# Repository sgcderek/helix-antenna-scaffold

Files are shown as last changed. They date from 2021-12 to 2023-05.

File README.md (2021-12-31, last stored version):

This repository contains the major versions of the dereksgc helical antenna scaffold OpenSCAD files. These can be used to generate a completely customized scaffold for a helical antenna of any application (HRPT dish feed, Inmarsat antenna, Wifi, FPV, ...).

Short summary of each version included:

**Version 5 - LATEST**  
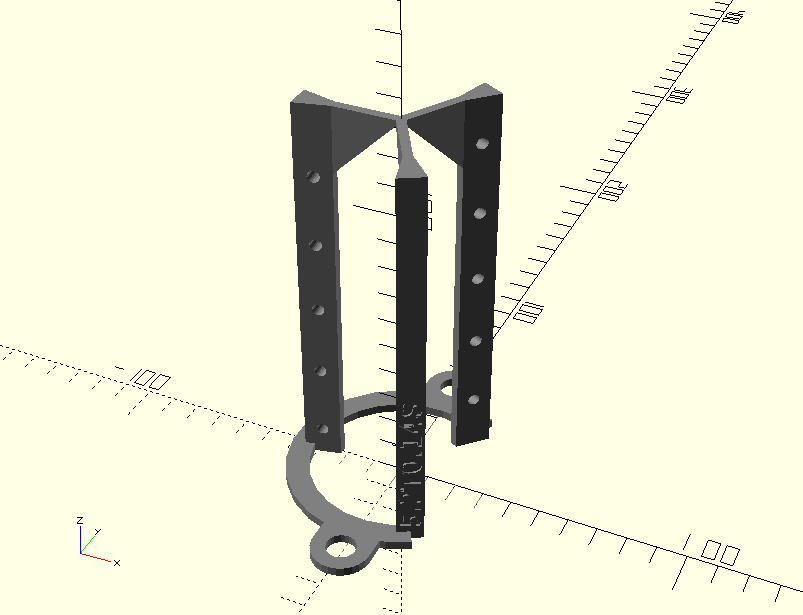
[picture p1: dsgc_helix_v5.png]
  
Created with Thingiverse online customizer in mind; a lot of (imo useless) features from v4 were dropped in favor of cleaner code and much faster rendering time. Parameters easier to understand and more straight-forward to use, the code should also be more readable and easier to edit. **It is recommended to use this version unless you require a specific feature from an older one.**

**Version 4**  
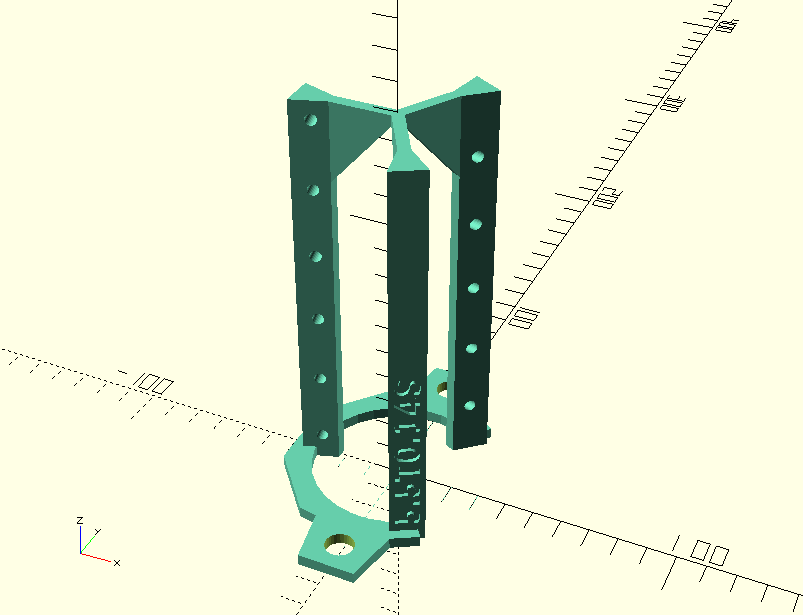
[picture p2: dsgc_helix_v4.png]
  
An improvement over v3 mainly meant to tackle a common issue with the support legs breaking. Uses up slightly more plastic and printing time in favor of a much more sturdy construction. Also comes with more customization parameters.

**Version 3**  
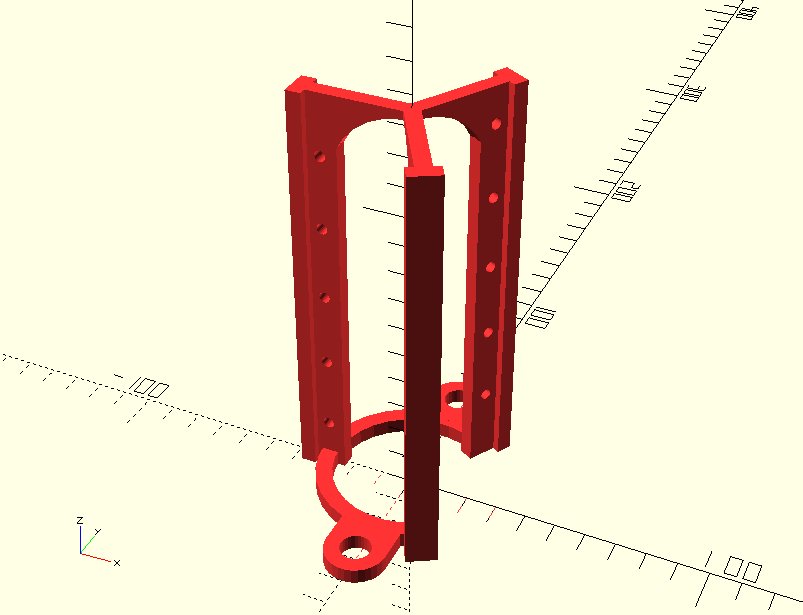
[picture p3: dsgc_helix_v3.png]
  
Initial recreation of the former scaffolds made manually and individually in Fusion 360. Probably don't use this anymore.

*Versions 1 and 2 were one-offs made in Fusion 360 on an individual basis*

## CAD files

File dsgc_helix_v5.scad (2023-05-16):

/*
* dereksgc customizable helical antenna scaffold v5
* Changes can be tracked at https://github.com/sgcderek/dsgc-helix-scaffold/blob/funny/dsgc_helix_v5.scad
* Check the repo for future updated versions
*/

/* [Basic settings] */

// Operating frequency of the helix
Frequency = 1700;

// Spacing between turns (wl)
Spacing = 0.14;

// Number of turns of the helix
Turns = 6;

// Polarization of the helix
Polarization = "LHCP"; //[RHCP,LHCP]

// Diameter of the holes for the helix conductor (mm)
Cutout_diameter = 4;

// How much of the first turn is parallel to the reflector
Parallel_turn = 0.25;

// Face number (OpenSCAD/Customizer parameter)
$fn = 50;

/* [Leg settings] */

// Width of the inner leg wall (mm)
Inner_leg_width = 4;

// Width of the outer leg wall (mm)
Outer_leg_width = 13;

// Distance between inner and outer leg walls (mm)
Leg_wall_distance = 12;

// Type of leg cross-section to extrude
Leg_type = "T-Beam"; //[Trapezoid,T-Beam,H-Beam]

/* [Base settings] */

// Base width (mm)
Base_width = 10;

// Base thickness (mm)
Base_thickness = 4;

// Cut out a third of the base (space for matching, connector, etc.)
Enable_cutout = true;

/* [Strut settings] */

// Thicknes of the top part of each strut (mm)
Strut_thickness = 3;

// Angle at which struts are generated (deg)
Strut_angle = 55;

// Generate a strut at the base of the scaffold
Bottom_strut = true;

// How much to shift the bottom strut up (mm)
Bottom_strut_offset = 0;

// Generate a strut in the middle of the scaffold (recommended for tall scaffolds)
Middle_strut = true;

// Generate a strut at the top of the scaffold (recommended for most scaffolds)
Top_strut = true;

// How much to shift the top strut down (mm)
Top_strut_offset = 0;

/* [Mounting settings] */

// Distance between the two mounting holes (mm)
Mounting_separation = 90;

// Diameter of the mounting holes (mm)
Mounting_diameter = 10;

// Thickness of the rim around each mounting hole (mm)
Mounting_thickness = 5;

// Rotational offset of the mounting holes (deg)
Mounting_rotation = 0;

/* [Text settings] */

// Enable engraved ID and decoration text
Enable_text = true;

// Custom decoration text (set to none to disable)
Decoration_text = "DEREKSGC";

// Depth of the text engraving (mm)
Text_depth = 0.75;

// Modifies the size of the text (can be lowered if text is too long)
Text_size_multiplier = 0.8;

/* [Hidden] */

// RGB value applied to the model render (won't affect stl).
Scaffold_color = [0.5,0.5,0.5];

// Polarization modifier (RHCP = 1, LHCP = -1)
Pol_modifier = (Polarization == "RHCP") ? 1 : -1;

// This rounds down the turn number to not render too much unused scaffold area (somehow?)
Turns_rounded = floor((Turns+0.01)/(1/3))*(1/3)-(1/6);

// Speed of light (m/s)
C = 299792458;

// Wavelength of the helix frequency (mm)
Wavelength = C/Frequency/1000;

// Diameter of the helix (mm)
Diameter = Wavelength/PI;

// Distance between turns (mm)
Spacing_distance = Wavelength*Spacing;

// Circumference of the helix (mm)
Circumference = PI*Diameter;

// Helix pitch (deg)
Pitch = atan(Spacing_distance/Circumference)*Pol_modifier;

// Calculate total number of segments in helix
Total_segments = Turns * 3;

// Calculate the length of each segment (slightly longer than longest leg dimension, mm)
Segment_height = max(Inner_leg_width, Outer_leg_width)*1.1;

// Calculate offset of the bottom corner of the strut base from the desired overhang angle
Strut_offset = ((Diameter/2)/tan(Strut_angle))-Leg_wall_distance/2;

// Total scaffold height (mm)
Total_height = (Turns_rounded*Spacing_distance+Cutout_diameter*3)-Spacing_distance*Parallel_turn;

// Font used for the text on the leg
Text_font = "DejaVu Sans:style=Bold";

// Size of the text
Text_size = Outer_leg_width*0.75*Text_size_multiplier;

// Shortened polarization text
Polarization_label = (Polarization == "RHCP") ? "R" : "L";

// Frequency text
Text_frequency = str(Frequency,Polarization_label);

// ID text
Text_ID = str(round(Turns_rounded*10)/10, "T", Spacing, "S");

// Difference between legs and leg cutouts
difference(){

    // Generate legs
    for (Leg = [1:1:3]){
        
        // Rotate each leg in place (120° increments)
        rotate([0,0,Leg*120-60])
            
        // Translate each leg in place
        translate([Diameter/2,0,0])
            
        // Face leg inwards
        rotate([0,0,-90])
        
        // Leg union
        union(){
        
            // Extrude leg from base polygon
            color(Scaffold_color)
            linear_extrude(height=Total_height){
                
                // Leg base polygon
                if (Leg_type == "Trapezoid"){
                    polygon([
                    [-Outer_leg_width/2,Leg_wall_distance/2],
                    [Outer_leg_width/2,Leg_wall_distance/2],
                    [Inner_leg_width/2,-Leg_wall_distance/2],
                    [-Inner_leg_width/2,-Leg_wall_distance/2]
                    ]);
                }
                else if (Leg_type == "T-Beam"){
                    polygon([
                    [-Outer_leg_width/2,Leg_wall_distance/2],
                    [Outer_leg_width/2,Leg_wall_distance/2],
                    [Outer_leg_width/2,(Leg_wall_distance/2)-Inner_leg_width],
                    [Inner_leg_width/2,(Leg_wall_distance/2)-Inner_leg_width],
                    [Inner_leg_width/2,-Leg_wall_distance/2],
                    [-Inner_leg_width/2,-Leg_wall_distance/2],
                    [-Inner_leg_width/2,(Leg_wall_distance/2)-Inner_leg_width],
                    [-Outer_leg_width/2,(Leg_wall_distance/2)-Inner_leg_width]
                    ]);
                }
                else if (Leg_type == "H-Beam"){
                    polygon([
                    [-Outer_leg_width/2,Leg_wall_distance/2],
                    [Outer_leg_width/2,Leg_wall_distance/2],
                    [Outer_leg_width/2,(Leg_wall_distance/2)-Inner_leg_width],
                    [Inner_leg_width/2,(Leg_wall_distance/2)-Inner_leg_width],
                    [Inner_leg_width/2,-((Leg_wall_distance/2)-Inner_leg_width)],
                    [Outer_leg_width/2,-((Leg_wall_distance/2)-Inner_leg_width)],
                    [Outer_leg_width/2,-Leg_wall_distance/2],
                    [-Outer_leg_width/2,-Leg_wall_distance/2],
                    [-Outer_leg_width/2,-((Leg_wall_distance/2)-Inner_leg_width)],
                    [-Inner_leg_width/2,-((Leg_wall_distance/2)-Inner_leg_width)],
                    [-Inner_leg_width/2,(Leg_wall_distance/2)-Inner_leg_width],
                    [-Outer_leg_width/2,(Leg_wall_distance/2)-Inner_leg_width]
                    ]);
                }
                
            }
            
            // Vertical position of the top strut
            Top_strut_z = Top_strut ? Total_height-Strut_thickness-Top_strut_offset : Total_height-Strut_thickness;
            
            // Vertical position of the top strut
            Bottom_strut_z = Bottom_strut ? Bottom_strut_offset : 0;
            
            // Vertical position of the mid strut
            Middle_strut_z = (Top_strut_z - Bottom_strut_z)/2+Bottom_strut_z;
            
            if (Bottom_strut){
                // Difference between bottom strut and cutout
                difference(){
                    // Translate and rotate bottom strut
                    translate([Inner_leg_width/2,-Leg_wall_distance/2,Bottom_strut_z])
                    rotate([0,270,0])
                    
                    // Extrude bottom strut
                    color(Scaffold_color)
                    linear_extrude(height=Inner_leg_width){
                    
                        // Bottom strut polygon
                        polygon(points=[
                            [0-Strut_offset,0],
                            [Strut_thickness,0],
                            [Strut_thickness,-Diameter/2+Leg_wall_distance/2],
                            [0,-Diameter/2+Leg_wall_distance/2]
                        ]);
                    }
                    // Cutouts to prevent the bottom strut from going into negative height
                    rotate([0,180,0])
                    color(Scaffold_color)
                    cylinder(d=Diameter,h=Diameter/2+Leg_wall_distance/2);
                }
            }
            
            if (Top_strut){
                // Translate and rotate top strut
                translate([Inner_leg_width/2,-Leg_wall_distance/2,Top_strut_z])
                rotate([0,270,0])
                
                // Extrude top strut
                color(Scaffold_color)
                linear_extrude(height=Inner_leg_width){
                
                    // Top strut polygon
                    polygon(points=[
                        [0-Strut_offset,0],
                        [Strut_thickness,0],
                        [Strut_thickness,-Diameter/2+Leg_wall_distance/2],
                        [0,-Diameter/2+Leg_wall_distance/2]
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

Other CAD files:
dsgc_helix_v3.scad
dsgc_helix_v4.scad
old/dsgc_helix_v3.scad
old/dsgc_helix_v4.scad

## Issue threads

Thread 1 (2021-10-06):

Just curious

Anjum9694, 2021-10-06:
Hello,
You've mentioned in the latest thing (Helical antenna scaffold set (v4)) about custom generated OpenSCAD having a chance of bad stuff happening.. Just wondering what sort of bad stuff? Because I've generated and printed a helical and wondering if it may also may be bad (btw I generated from the original script not v4)

sgcderek, 2021-10-06:
If it printed and it looks ok then it probably is ok. The new script lacks measures to prevent the scaffold from generating poorly when abnormal parameters are used, such as a very high/low frequency or weird mounting footprints. Usually this ends up just being aesthetic and can be fixed by poking the scaffold with a soldering iron but still that's something I want to prevent

Closed 2021-10-06.

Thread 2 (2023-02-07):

Helical not receiving well with grid parabolic ant.

Tim-Deefield, 2023-02-07:
Hi Derek,

First thanks for your "Beginners Guide to HRPT", it is fantastic!   I have been about 90% successful receiving HRPT images because of your info.  The best images have been received using the Nooelec grid parabolic and linear feed.  I have been trying for several weeks to use your helical feed with the 3D printed support.  I want the extra gain it provides as well as the circular polarization.

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

I am working the NOAA 18 & 19 HRPT satellites and no matter what I try the images are noisey and indicate low gain on the antenna, compared to the linear feed.  I carefully built the LHCP & RHCP versions of your 3D supports and I believe the helicals themselves are working well.  The problem seems to be related to using the helicals with the grid parabolic.   Has anyone else used your helicals with the grid parabolic ant?  To find the focal point I radiated a 1.7 GHz signal with RHCP helical ant pointed at the grid parabolic /LHCP helical.  I moved the LHCP feed in and out and found the strongest signal and then mounted it at that point.

I'm really baffled why it does not perform very well and thought it would really out perform the linear feed.

Any ideas what I might be doing wrong?

If you know anyone that has used the helical with the Nooelec or similar grid parabolic I would be interested in the mounting of the helical feed and the focal point measurements they used.

Thanks in advance for any suggestions.

-Tim Heffield
Florida, USA

sgcderek, 2023-05-16:
Hello, sorry for not responding earlier, I must have missed the email notification of this issue.
Grid dishes usually require a feed with a wider beam, so in case of a helix like this you could try reducing either the spacing or the number of turns.
Also, if I understand correctly, you found the focus by setting up your own local 1.7 GHz transmitter, that may not actually give you the "real" focus of the dish because the waves at such a short distance are not parallel, as they would be coming from a satellite. On the other hand, the difference probably would be quite small.

Tim-Deefield, 2023-05-21:
Hi Derek, Sorry for my slow response as well, I wanted to get some pics together to send  you.   I thought maybe it was a beam width issue and thank you for confirming this.  I have since had good results using a DIY Biquad feed for the grid parabolic.  I am still looking for a dish I can you use with the helical feed, to obtain the additional gain.

Here are some pics of the Biquad feed and an HRPT image I received with this configuration.

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

sgcderek, 2023-05-21:
I've had good results with a biquad as well, though in my case with an offset dish the helix still works better. Consider giving a different helix a shot, a biquad is a linearly polarized antenna so you will be losing a few dB (but as you can tell it's not really a big deal)

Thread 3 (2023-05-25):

3D base printing problem

bennybo, 2023-05-25:
Hello Derek, I exported the drawing on openscad as an STL and printed on my 3d printer but the base came out as shown in the picture attached. Is there a setting I am not aware of that needs to be tweaked? Thanks for such a wonderful piece of software.

Thanks,
Brian.
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

sgcderek, 2023-05-25:
Honestly I have no idea how this could have happened. Would it be possible for you to share the parameters you used, the OpenSCAD version you have, and the slicer you're using? It looks like an issue with the slicer software to me

bennybo, 2023-05-25:
I found it. Its a box lid from a previous project. I didn't clear the workspace from a previous project. My bad.

sgcderek, 2023-05-25:
No worries, especially when working with OpenSCAD and how it handles 2D extrusions things can sometimes get confusing

Closed 2023-05-25.

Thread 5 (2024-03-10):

915 MHz helical has no mounting holes ?

zanco, 2024-03-10:
For the LoRa satellite at 915 MHz I decided to try if an 915 MHz RHCP helical would fit on my printer bed. Fitted nicely, together with one RHCP 2250 3 turns and one LHCP 2250 3 turns.

Only just after the print., when removing the holders from the printing bed I noticed the 915 MHz helical has no mounting holes

Not a big problem , I might even use hotglue to fix it to the reflector, of even clips or tyraps, but I am wondering why this happened.

Only thing I changed was the strut thickness, from 1 to 2 but reverting that does not give me mounting holes ;-)
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

Somewhere around 1400 MHz the mounting ears get part of the ring and below 1100 MHz there are not even holes left.
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

Maybe you can find a solution, thanks

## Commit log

2021-07-19 Code cleanup and hole clip option
    [dsgc_helix_scaffold.scad]
2021-07-19 Added hole clip description
2021-07-19 Added experimental wideband helix scaffold file
    [dsgc_wb-helix_scaffold.scad]
2021-07-19 Allow mounting footprint lower than helix diameter
    [dsgc_helix_scaffold.scad, dsgc_wb-helix_scaffold.scad]
2021-07-19 Cut off excess leg material
    [dsgc_wb-helix_scaffold.scad]
2021-07-20 Print dimensions in console
    [dsgc_helix_scaffold.scad]
2021-07-20 Added stacking support option
    [dsgc_helix_scaffold.scad]
2021-09-05 Increased default leg and base width
    [dsgc_helix_scaffold.scad]
2021-09-05 Increase hole diameter to correct for print shrink/sag
    [dsgc_helix_scaffold.scad]
2021-09-18 Added 4th scaffold version script
    [dsgc_helix_v4.scad]
2021-10-02 Honestly I forgot what I changed just look at the diff
    [dsgc_helix_v4.scad]
2021-12-30 Unified color and info text, added links to repo
    [dsgc_helix_v3.scad, dsgc_helix_v4.scad, dsgc_helix_v5.scad]
2021-12-31 Updated info, unified mounting separation with v5
    [dsgc_helix_v3.scad]
2021-12-31 Updated info
    [dsgc_helix_v4.scad]
2022-01-02 Added options to offset top and bottom struts
    [dsgc_helix_v5.scad]
2022-01-02 Disable bottom and mid struts by default
    [dsgc_helix_v5.scad]
2022-01-02 Mid strut ignores offsets of disabled struts
    [dsgc_helix_v5.scad]
2022-01-02 Add two new leg types and selector
    [dsgc_helix_v5.scad]
2022-01-02 Make T-Beam legs the default
    [dsgc_helix_v5.scad]
2022-01-02 Increase default leg outer width
    [dsgc_helix_v5.scad]
2023-05-16 Tweak default params + add mntng rotation
    [dsgc_helix_v3.scad, dsgc_helix_v4.scad, dsgc_helix_v5.scad]
